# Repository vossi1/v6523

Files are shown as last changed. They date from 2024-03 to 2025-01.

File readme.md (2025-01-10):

# V6523 - Replacement for a 6523 or 6525 without IRQ Controller (CBM2 keyboard TPI)  

**Copyright (c) 2024 Vossi - v.1 / v.2 (C64 IEEE option)**

**www.mos6509.com**

## License
This work is licensed under a Creative Commons Attribution-ShareAlike 4.0
International License. See [https://creativecommons.org/licenses/by-sa/4.0/](https://creativecommons.org/licenses/by-sa/4.0/).

:thumbsup: v.2 now with C64 IEEE488 Interface support (use special IEEE hdl-code)!

:pushpin: At JLC you have to select: Remove Order Number = "Specify a location"

**[Schematic](https://github.com/vossi1/v6523/blob/master/v6523_v2.png)**

**[Parts](https://github.com/vossi1/v6523/blob/master/parts.txt)**

**CPLD-Firmware:** The .JED file can be uploaded with a JTAG-SMT2 Xilinx programmer (China) and [xc3sprog](https://xc3sprog.sourceforge.net/)

:exclamation: **BEWARE: I got good CPLD's from China but there are some XC9572XL FAKES out there**

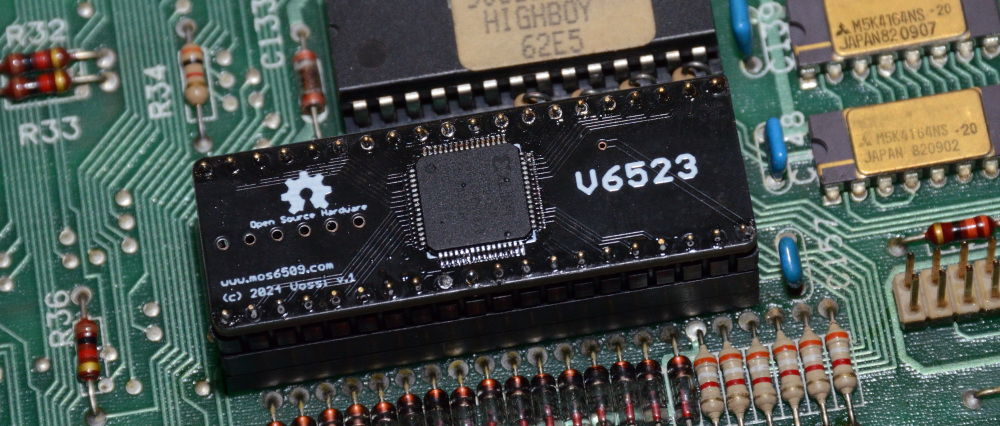
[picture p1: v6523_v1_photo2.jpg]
V6523 720-photo

cbm 720 (the very first V6523 on the photo misses the pin1 side notch)

:white_check_mark: **Tested successful in cbm620, 720 and P500 with:** Diagnostic-ROM and my fingers :wink:

:x: **Does not work in 1551, C64-Magic Voice, CDTV (A570)**

You have to solder a wire to pin 10 of the 74LS08 (PHI2): (sadly I forgot the "specify a location" option :wink: )

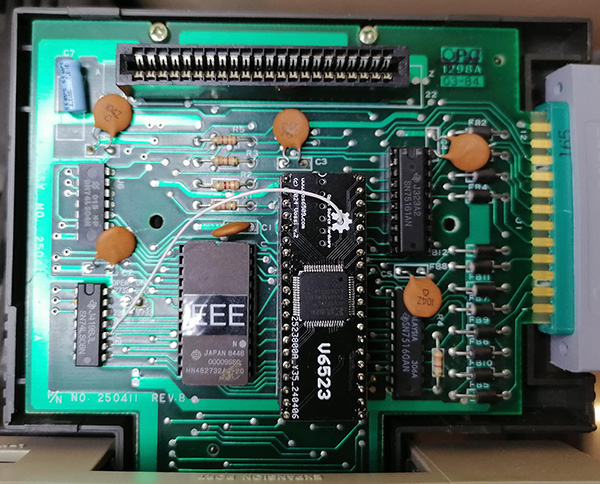
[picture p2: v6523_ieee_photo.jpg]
V6523 ieee-photo


I added this logic for the IEEE support to the v.2 version:

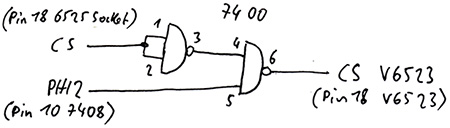
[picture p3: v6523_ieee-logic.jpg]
V6523 ieee-logic


REASON: Commodore didn't combined CS with PHI2 like in the CBM2 machines.
According to the datasheet for the 6525, they should have done that.
I don't know why it still works with the 6525 in the IEEE interface?

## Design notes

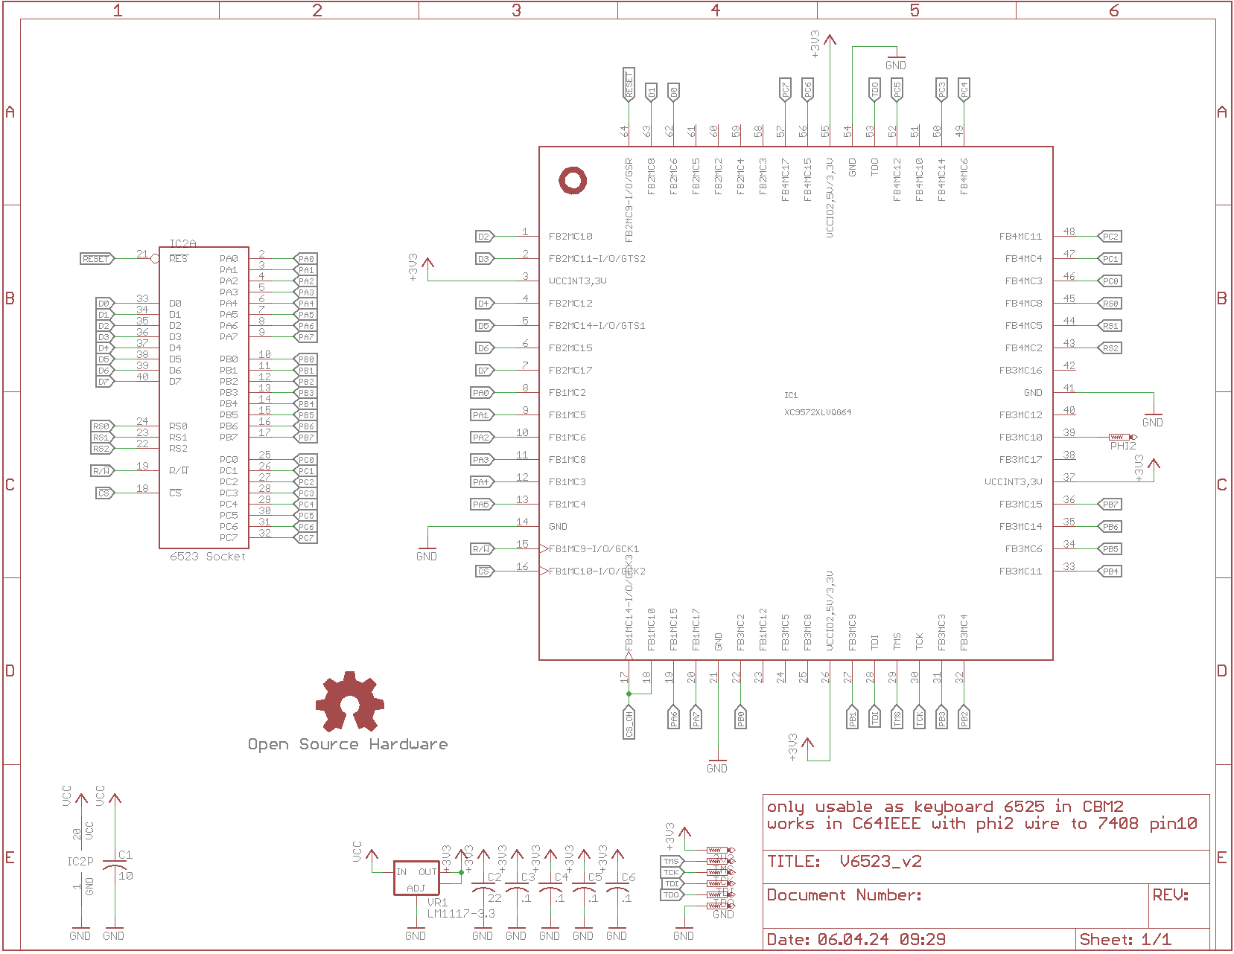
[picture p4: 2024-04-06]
v6523_v2.png

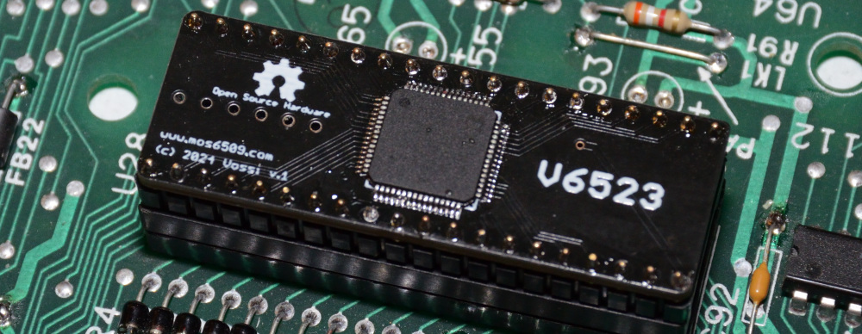
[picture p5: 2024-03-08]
v6523_v1_photo.jpg

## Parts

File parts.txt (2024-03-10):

Part      Value              Device

C1        10u / 10V          C0805
C2        22u / 6.3V         C0805
C3-C6     100n               C0603
IC1       XC9572XL-10VQ64C   VQFP64
VR1       LM1117-3.3         SOT223

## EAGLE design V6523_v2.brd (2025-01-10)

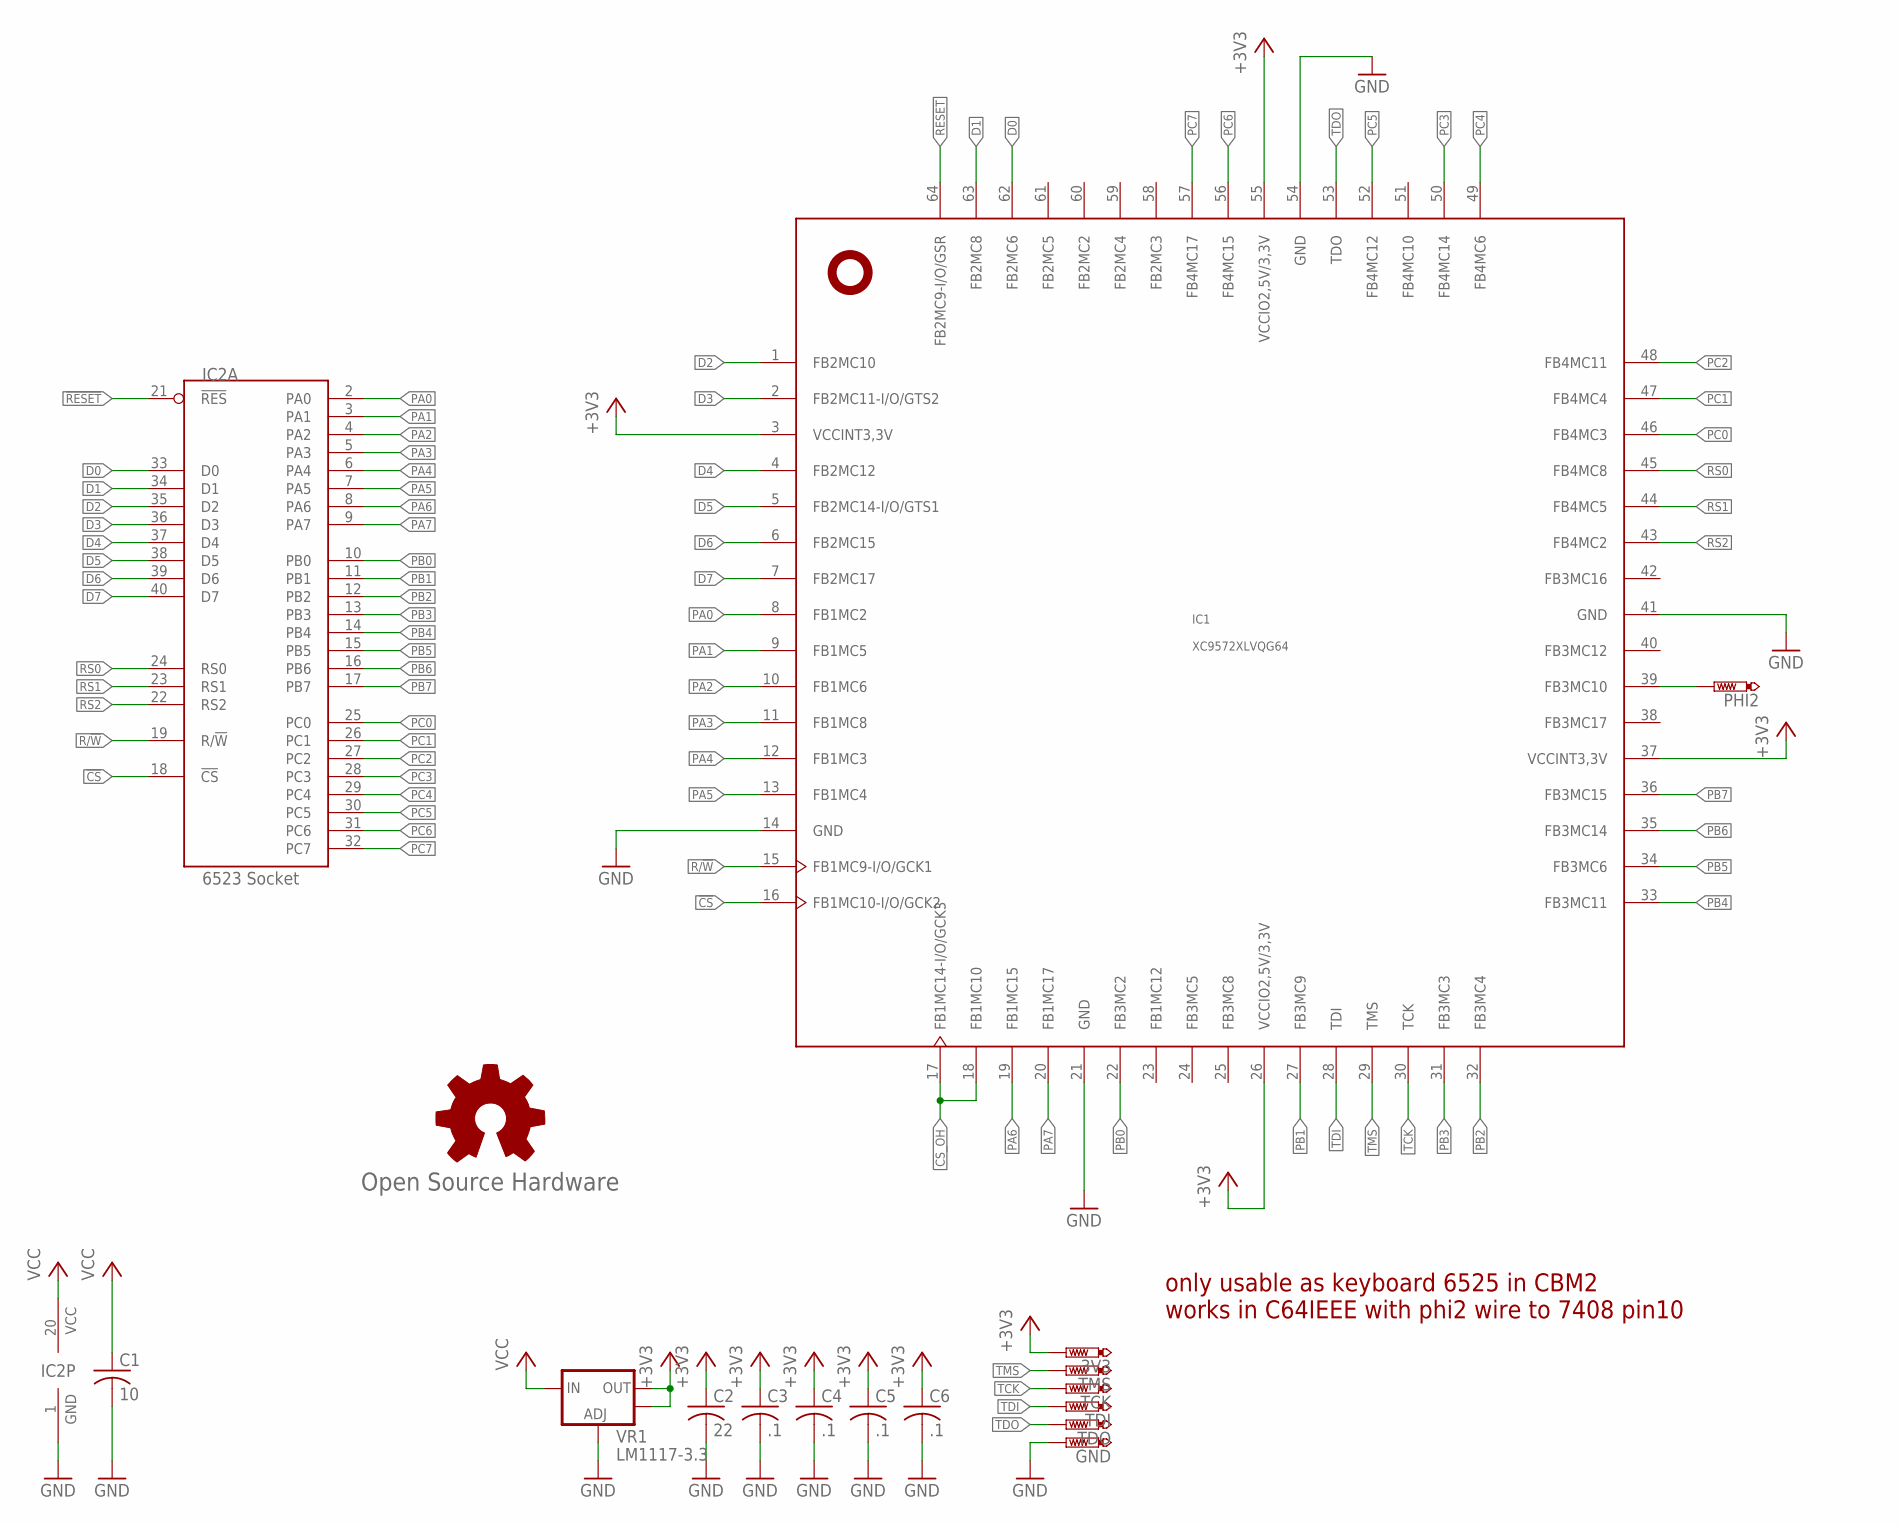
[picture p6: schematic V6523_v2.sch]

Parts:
3V3: PTR1TP08R; TP08R
C1: 10; C0805
C2: 22; C0805
C3, C4, C5, C6: .1; C0603
GND: PTR1TP08R; TP08R
GOLD_ORB_SM1: Open Source Hardware; OSHW_5MM
IC1: XC9572XLVQG64; VQFP64
IC2: 6523 Socket; DIL40-RP-NOFRAME
PHI2: PTR1TP08R; TP08R
TCK: PTR1TP08R; TP08R
TDI: PTR1TP08R; TP08R
TDO: PTR1TP08R; TP08R
TMS: PTR1TP08R; TP08R
VR1: LM1117-3.3; SOT223

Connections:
!CS: IC1.16 (FB1MC10-I/O/GCK2), IC2.18 (!CS)
!RESET: IC1.64 (FB2MC9-I/O/GSR), IC2.21 (!RES)
+3V3: 3V3.TP, C2.1, C3.1, C4.1, C5.1, C6.1, IC1.3 (VCCINT3,3V), IC1.26 (VCCIO2,5V/3,3V), IC1.37 (VCCINT3,3V), IC1.55 (VCCIO2,5V/3,3V), VR1.2 (OUT), VR1.4 (OUT)
CS_OH: IC1.17 (FB1MC14-I/O/GCK3), IC1.18 (FB1MC10)
D0: IC1.62 (FB2MC6), IC2.33 (D0)
D1: IC1.63 (FB2MC8), IC2.34 (D1)
D2: IC1.1 (FB2MC10), IC2.35 (D2)
D3: IC1.2 (FB2MC11-I/O/GTS2), IC2.36 (D3)
D4: IC1.4 (FB2MC12), IC2.37 (D4)
D5: IC1.5 (FB2MC14-I/O/GTS1), IC2.38 (D5)
D6: IC1.6 (FB2MC15), IC2.39 (D6)
D7: IC1.7 (FB2MC17), IC2.40 (D7)
GND: C1.2, C2.2, C3.2, C4.2, C5.2, C6.2, GND.TP, IC1.14 (GND), IC1.21 (GND), IC1.41 (GND), IC1.54 (GND), IC2.1 (GND), VR1.1 (ADJ)
PA0: IC1.8 (FB1MC2), IC2.2 (PA0)
PA1: IC1.9 (FB1MC5), IC2.3 (PA1)
PA2: IC1.10 (FB1MC6), IC2.4 (PA2)
PA3: IC1.11 (FB1MC8), IC2.5 (PA3)
PA4: IC1.12 (FB1MC3), IC2.6 (PA4)
PA5: IC1.13 (FB1MC4), IC2.7 (PA5)
PA6: IC1.19 (FB1MC15), IC2.8 (PA6)
PA7: IC1.20 (FB1MC17), IC2.9 (PA7)
PB0: IC1.22 (FB3MC2), IC2.10 (PB0)
PB1: IC1.27 (FB3MC9), IC2.11 (PB1)
PB2: IC1.32 (FB3MC4), IC2.12 (PB2)
PB3: IC1.31 (FB3MC3), IC2.13 (PB3)
PB4: IC1.33 (FB3MC11), IC2.14 (PB4)
PB5: IC1.34 (FB3MC6), IC2.15 (PB5)
PB6: IC1.35 (FB3MC14), IC2.16 (PB6)
PB7: IC1.36 (FB3MC15), IC2.17 (PB7)
PC0: IC1.46 (FB4MC3), IC2.25 (PC0)
PC1: IC1.47 (FB4MC4), IC2.26 (PC1)
PC2: IC1.48 (FB4MC11), IC2.27 (PC2)
PC3: IC1.50 (FB4MC14), IC2.28 (PC3)
PC4: IC1.49 (FB4MC6), IC2.29 (PC4)
PC5: IC1.52 (FB4MC12), IC2.30 (PC5)
PC6: IC1.56 (FB4MC15), IC2.31 (PC6)
PC7: IC1.57 (FB4MC17), IC2.32 (PC7)
PHI2: IC1.39 (FB3MC10), PHI2.TP
R/!W: IC1.15 (FB1MC9-I/O/GCK1), IC2.19 (R/!W)
RS0: IC1.45 (FB4MC8), IC2.24 (RS0)
RS1: IC1.44 (FB4MC5), IC2.23 (RS1)
RS2: IC1.43 (FB4MC2), IC2.22 (RS2)
TCK: IC1.30 (TCK), TCK.TP
TDI: IC1.28 (TDI), TDI.TP
TDO: IC1.53 (TDO), TDO.TP
TMS: IC1.29 (TMS), TMS.TP
VCC: C1.1, IC2.20 (VCC), VR1.3 (IN)

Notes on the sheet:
only usable as keyboard 6525 in CBM2 works in C64IEEE with phi2 wire to 7408 pin10

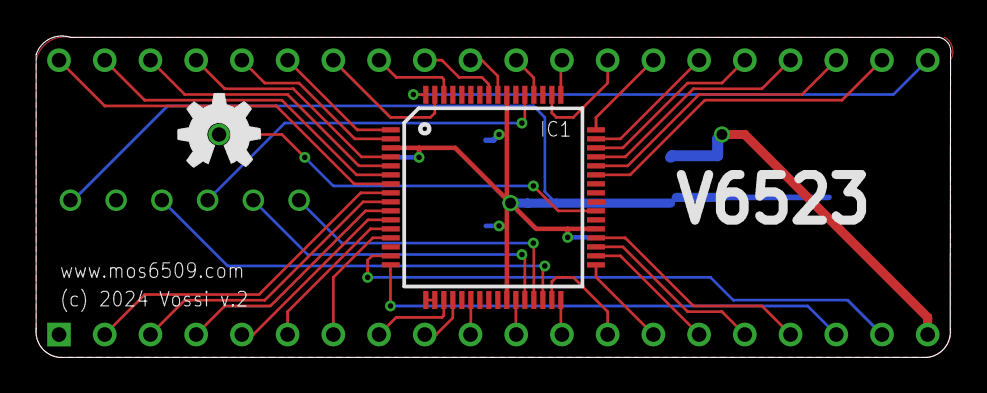
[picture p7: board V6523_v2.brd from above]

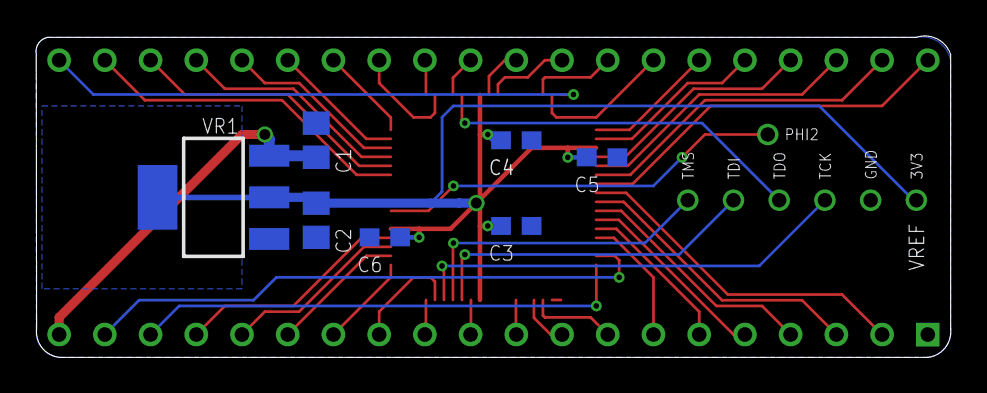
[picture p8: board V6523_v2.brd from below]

Board: 2 copper layers, 50.8 x 17.9 mm, 17 parts (13 on the bottom side), 47 nets.

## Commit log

2024-04-06 correction in gerbers v2
2024-04-06 v2 phi2 solderpoint for c64 ieee usage
2024-04-06 reuploaded gerber v1 because v2 is not tested
2025-01-10 added eagle files
    [V6523_v2.brd, V6523_v2.sch]

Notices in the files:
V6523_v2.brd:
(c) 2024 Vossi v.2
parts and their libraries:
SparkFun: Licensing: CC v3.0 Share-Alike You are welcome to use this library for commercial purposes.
